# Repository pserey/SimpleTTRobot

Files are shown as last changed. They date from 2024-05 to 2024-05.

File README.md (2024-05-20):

# Simple TT Robot

> **Warning: This project is still in its early stages. Expect frequent updates and potential breaking changes to the codebase. The first real release will be available on the [Releases](https://github.com/pserey/SimpleTTRobot/releases) page.**

This open-source Table Tennis Robot project is designed to be a realistic, affordable, and easy-to-build robot for training purposes. Below, links to various sections of this repository are available.

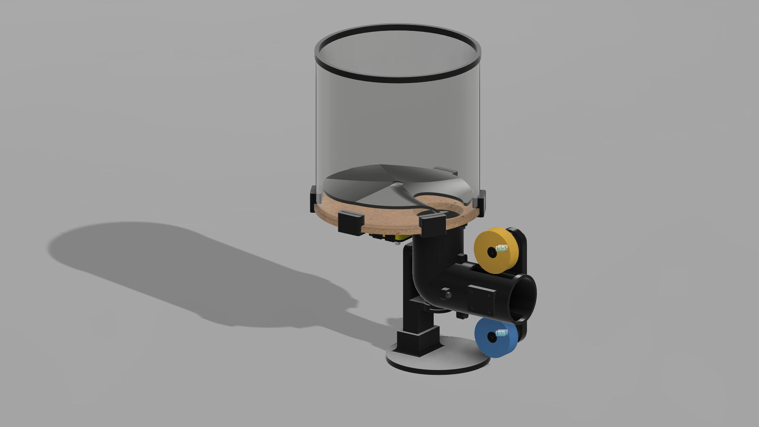
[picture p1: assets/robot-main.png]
robot

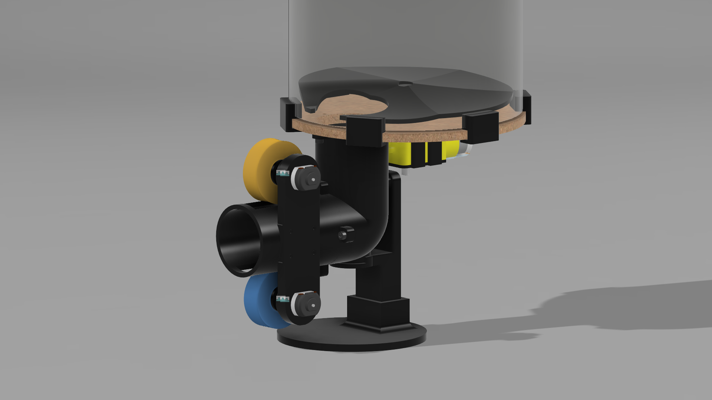
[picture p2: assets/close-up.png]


## Table of Contents

- [Introduction](#introduction)
- [Materials](#materials)
- [Build Guide](#build-guide)
- [Contributing](#contributing)
- [License](#license)

## Introduction

The Simple Table Tennis Robot was a personal project that tried to create a cheap alternative to every table tennis robot out there without losing on training capabilities. Now, the difference is it's an Open Source project 🏓

The main objective of this project is to use easy-to-find materials, electric components and microcontroller to make the building of it viable and cheap for anyone (mainly focused in the Brazilian market).

The whole design of the robot is heavily inspired in [this video](https://www.youtube.com/watch?v=-pSiuAdUKP4) from the channel [hiennguyenvan](https://www.youtube.com/@hiennguyenvan9777).

## Materials

### Physical/Hardware Materials
- 3D printed parts (CAD available)
- MDF laser-cut parts, or hand-cut if preferred (CAD available)
- IPong V300 flywheels (**the main focus now is developing non-propietary flywheels**)
- M3 and M4 screws and nuts
- Acrylic or cardboard sheets

### Electronic Components
- Arduino Nano or Uno microcontroller
- Connecting wires
- 1k and 2k resistors
- 2x 130-size 6V DC motors
- 1x 130-size 6V DC motor with gearbox
- 2x L298N H-Bridge motor drivers
- HC-05 Bluetooth receiver module
- LM393 Speed Sensor module
- 12V power supply

> Further detail of materials such as quantities will be added in a BOM format and updated at the README.md after the first release.

## Build Guide

> Build guide and circuit schema will be added with the first release. For now, only [build pictures](assets/build) are available.

## License

### CAD and documentation

The non-software components (3D CAD designs and documentation) are licensed under the Creative Commons Attribution-ShareAlike 4.0 International (CC BY-SA 4.0) License. See the [CAD-LICENSE](CAD-LICENSE.md) file for more details.

Shield: [][cc-by-sa]

This work is licensed under a
[Creative Commons Attribution-ShareAlike 4.0 International License][cc-by-sa].

[][cc-by-sa]

[cc-by-sa]: http://creativecommons.org/licenses/by-sa/4.0/
[cc-by-sa-image]: https://licensebuttons.net/l/by-sa/4.0/88x31.png
[cc-by-sa-shield]: https://img.shields.io/badge/License-CC%20BY--SA%204.0-lightgrey.svg

### Code

The software components of this project are licensed under the MIT License. See the [LICENSE](LICENSE.md) file for more details.

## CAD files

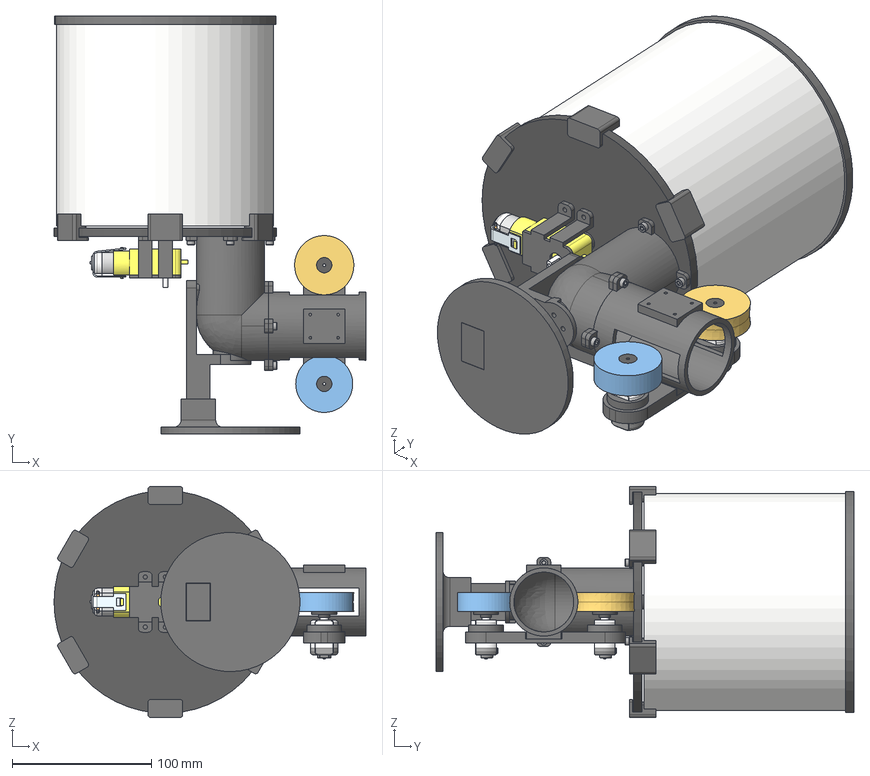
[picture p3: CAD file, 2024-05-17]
cad/step/Robot.step
224.2 x 300.5 x 166.1 mm
3V DC Electromotor x 2
Wheel Support
Wheel Support (1)
Entry Tube
Screws
Nuts
Base (1)
Disc
Motor Holder
Surface 1
Base (2)

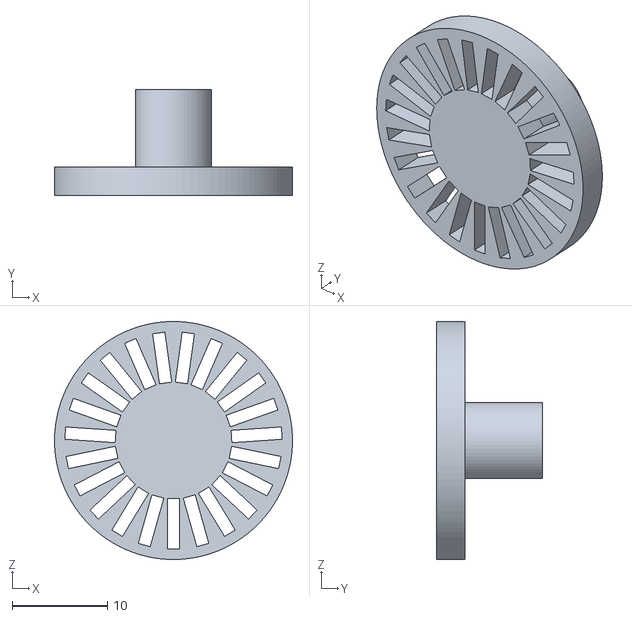
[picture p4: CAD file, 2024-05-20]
cad/stl/Encoder Wheel.stl
25.0 x 11.1 x 25.0

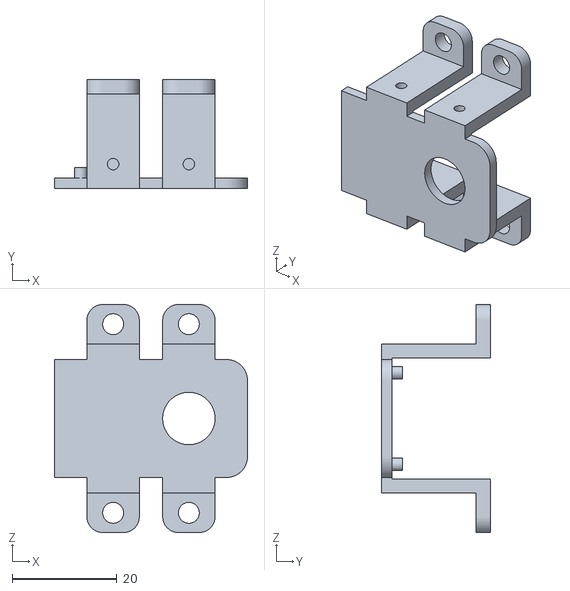
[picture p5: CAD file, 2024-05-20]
cad/stl/Motor Holder (Reservoir).stl
36.9 x 20.8 x 43.5

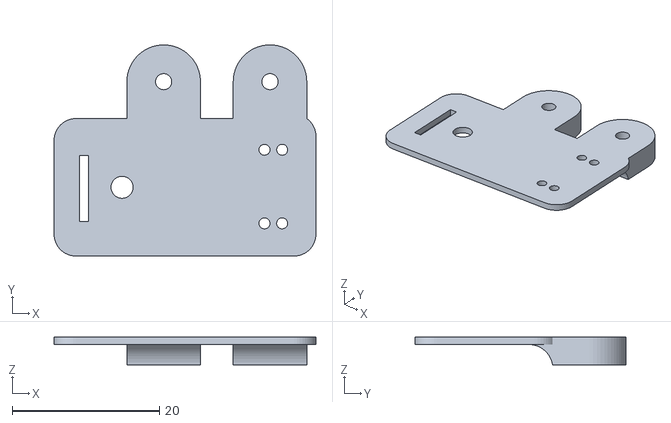
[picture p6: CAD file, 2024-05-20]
cad/stl/Encoder Support.stl
35.6 x 28.7 x 3.76

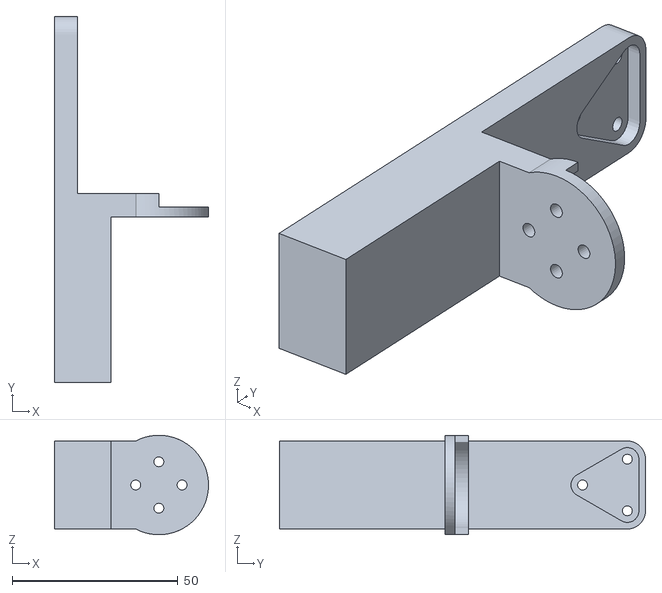
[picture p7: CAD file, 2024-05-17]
cad/stl/Base-Support.stl
46.5 x 110.5 x 30.0

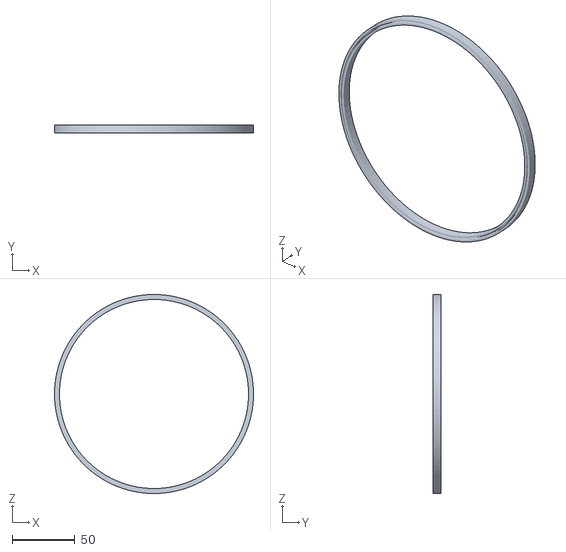
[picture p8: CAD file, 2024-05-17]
cad/stl/Wall Ring.stl
159.1 x 6.00 x 159.1

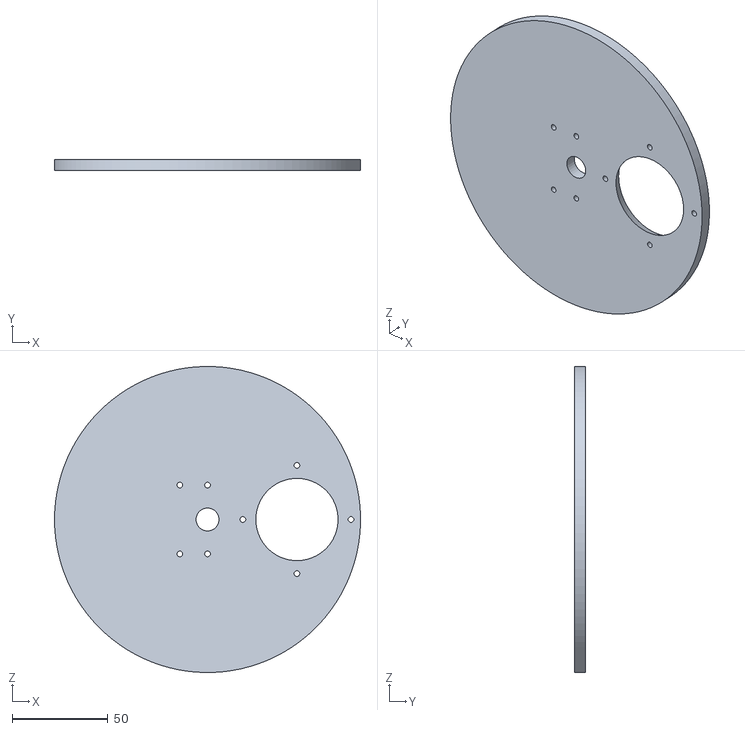
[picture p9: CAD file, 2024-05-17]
cad/stl/Reservoir Base.stl
160.0 x 6.00 x 160.0

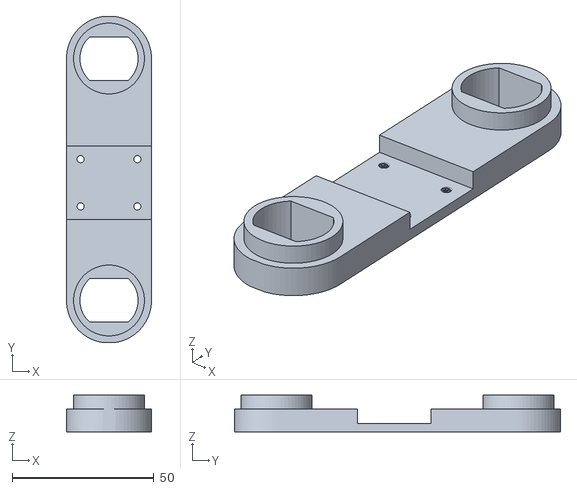
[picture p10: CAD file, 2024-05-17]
cad/stl/Motor Holder.stl
30.0 x 115.0 x 13.0

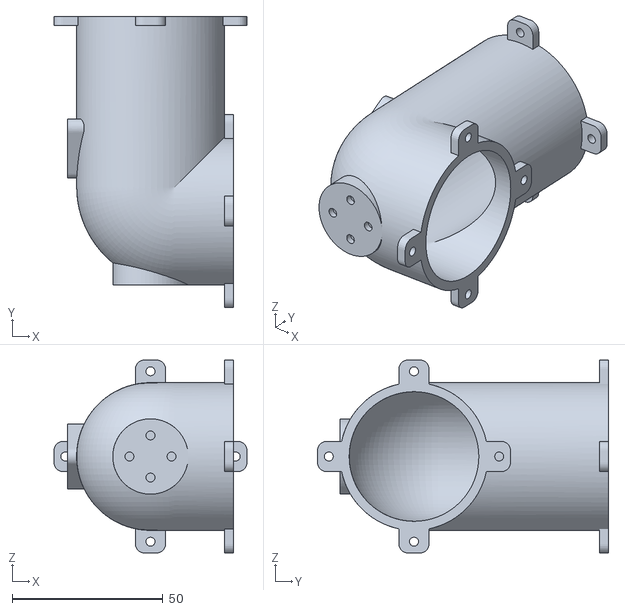
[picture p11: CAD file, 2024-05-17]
cad/stl/Entry Tube.stl
64.0 x 96.5 x 64.0

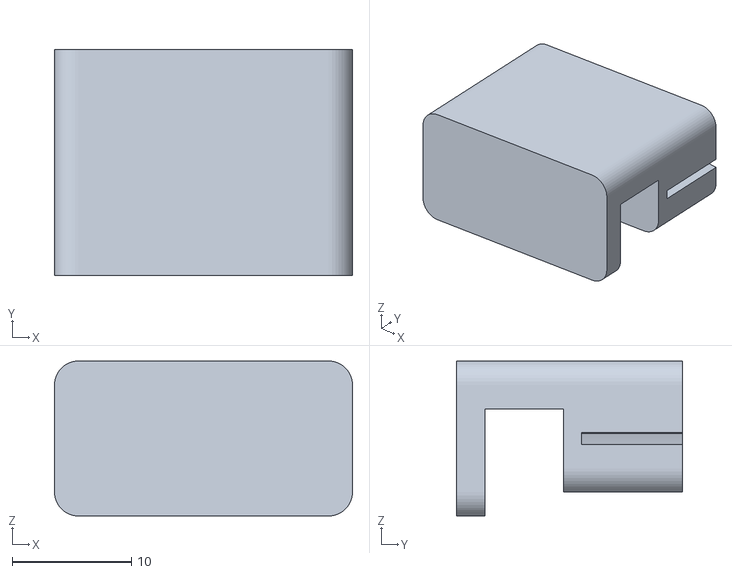
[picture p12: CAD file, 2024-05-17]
cad/stl/Wall Holder.stl
25.0 x 19.0 x 13.0

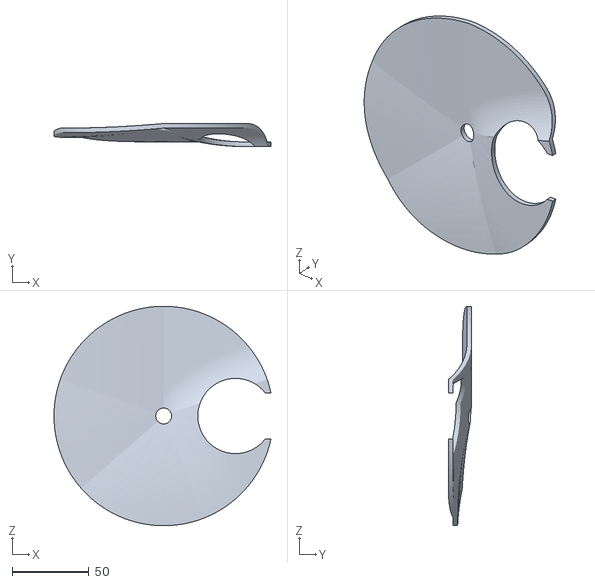
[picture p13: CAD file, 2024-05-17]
cad/stl/Disc.stl
141.4 x 15.0 x 143.0

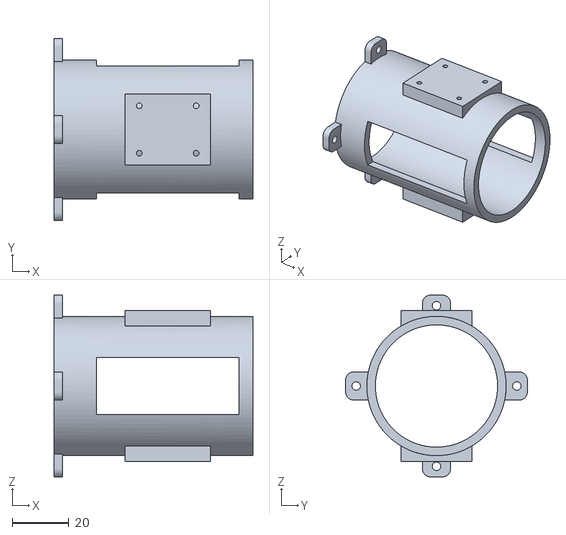
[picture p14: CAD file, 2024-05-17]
cad/stl/Motor Tube.stl
70.0 x 64.0 x 64.0

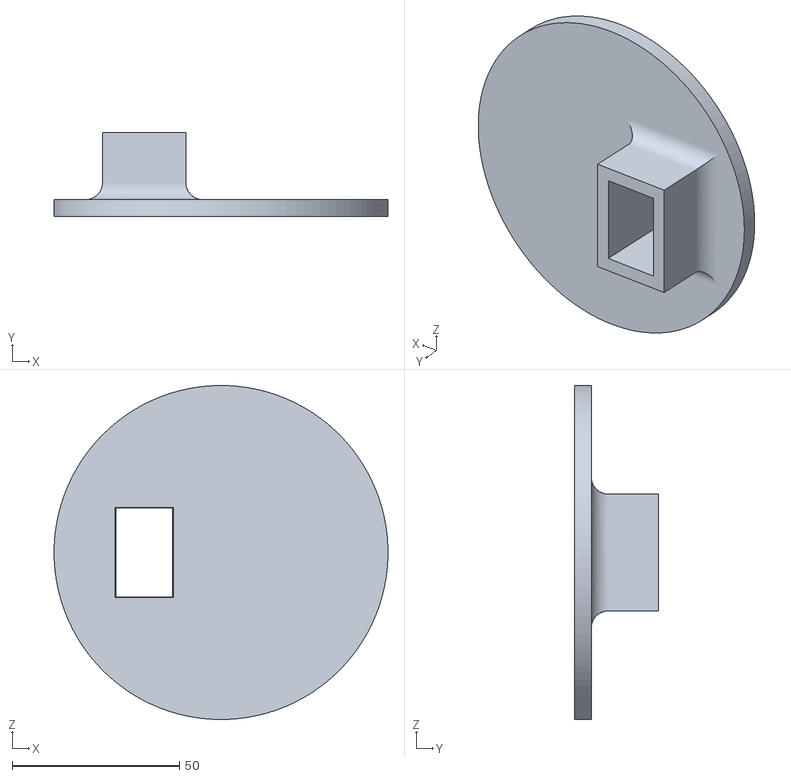
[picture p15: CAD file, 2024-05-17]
cad/stl/Base-Base.stl
100.0 x 25.0 x 100.0

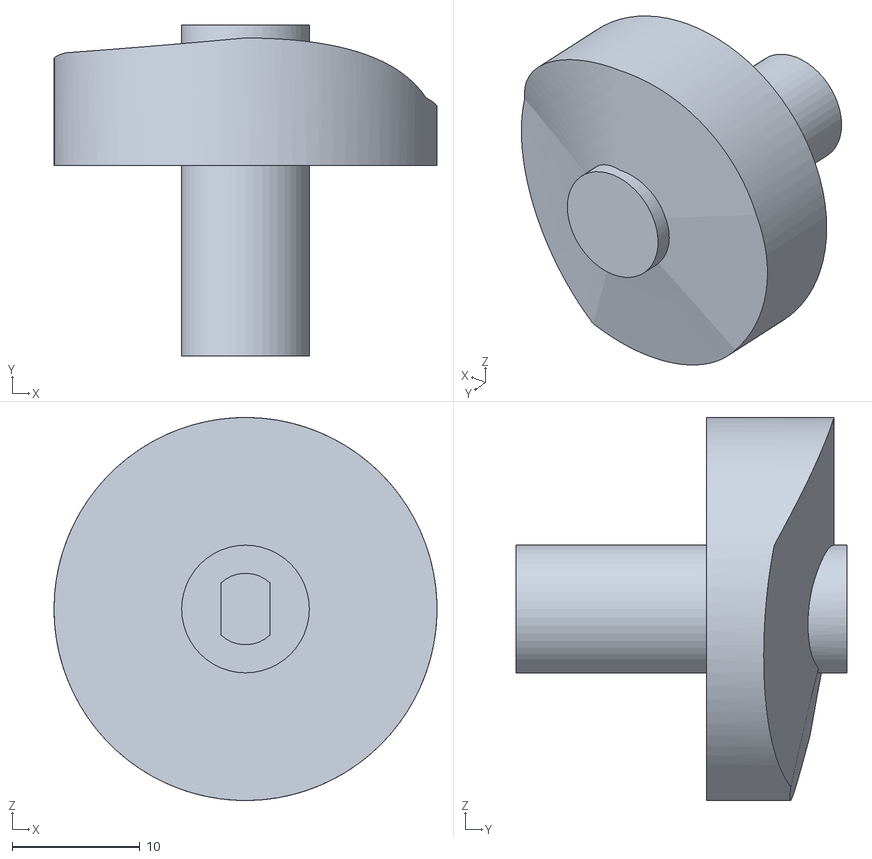
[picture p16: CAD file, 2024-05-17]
cad/stl/Pin.stl
30.0 x 25.9 x 30.0

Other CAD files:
cad/fusion/3V_DC_Electromotor.f3d
cad/fusion/Reduction_Box_Motor.f3d

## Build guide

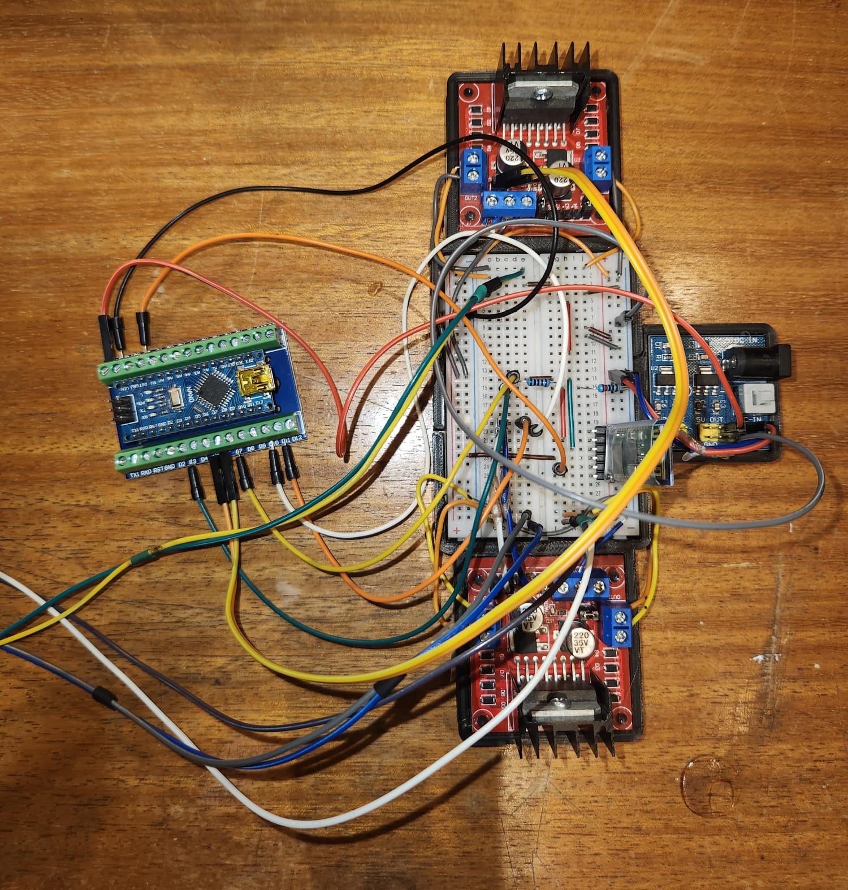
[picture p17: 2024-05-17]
assets/build/protoboard-build.jpg

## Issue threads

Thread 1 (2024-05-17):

Disc is not properly leading balls to shaft

pserey, 2024-05-17:
One of the "slices" of the disc is not inclined enough so that it leads the balls to the shaft. It results in making balls spin continuously on it without going to the shaft. A redesign using Fusion 360 is needed but I couldn't make it, so the current design uses fillets.

The problematic "slice" is the highlighted one.

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

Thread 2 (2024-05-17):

Reservoir base shaft might need to be larger

pserey, 2024-05-17:
The hole that connects the reservoir base to the entry tube seems to be too small. This results in the balls getting stuck between the disc and the edge of the hole when the disc spin frequency is high. Probably a bigger hole will solve this.

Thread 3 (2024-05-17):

Use non-proprietary flywheels

pserey, 2024-05-17:
It's **extremely** important that the flywheels are not proprietary like the ones being used currently. Testing materials with grip and elasticity such as TPU is needed to replace the current flywheels as soon as possible.

A copy of the IPong V300 wheels will work perfectly. After there is a working model, redesigns can be applied.

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

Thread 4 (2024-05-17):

Implement PID control over disc motor

pserey, 2024-05-17:
Implementing PID control over the disc motor is necessary to prevent balls stucking to the shaft, precision on frequency and adaptation to force needed with the increase of weight added with more balls.

pserey, 2024-05-20:
Simple PID control implemented in disc motor with LM393 speed sensor (optical encoder) with encoder disc. However, speed is still not 100% predictable and makes too high jumps.

- [ ] Needs implementation of PID tuning
- [ ] Encoder circuit support CAD file lacks precision (needed post processing)

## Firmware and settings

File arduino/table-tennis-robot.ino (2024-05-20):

#include "Arduino.h"
#include <SoftwareSerial.h>

const byte rxPin = 7;
const byte txPin = 3;
SoftwareSerial BTSerial(rxPin, txPin);

// define motor control pins (PWA)
const int back = 10;
const int top = 11; 

// frequency pins (PWA)
const int AFreq = 5;
const int BFreq = 6;

// encoder velocity
const int encPin = 2;
volatile int pulseCount = 0;
unsigned long previousMillis = 0;
const unsigned long interval = 500;
volatile int lastState = 0;

// PID
int globalRPM = 0;
const int targetRPM = 60;

// Kp, Ki, Kd
const float Kp = 0.75;
const float Ki = 0.2;
const float Kd = 0;

float previousError = 0;
float integral = 0;
float controlOutput = 0;

int topVel = 0;
int backVel = 0;
const int step = 5;
const int minVel = 25;
const int maxVel = 40;
int freqVelocity = 40;

// variables
int freqState = 0;
// at first implementation, i've decided to use string messages
// ending at ';' to communicate via HC-05
String messageBuffer = "";
String message = "";

int increaseVelocity(int velocity) {
  if (velocity < minVel) {
    return minVel;
  } else {

    if (velocity + step >= maxVel) {
      return maxVel;
    } else {
      return velocity + step;
    }
  }
}

int decreaseVelocity(int velocity) {
  if (velocity - step < minVel) {
    return 0;
  } else {
    return velocity - step;
  }
}

void startFrequency() {
  freqState = 1;

  analogWrite(AFreq, 40);
  delay(50);
  analogWrite(AFreq, freqVelocity);
}

void stopFrequency() {
  freqState = 0;
  analogWrite(AFreq, 0);
}

void unclogFrequency() {
  analogWrite(AFreq, 0);
  analogWrite(BFreq, 50);
  delay(70);
  analogWrite(BFreq, 0);
  startFrequency();
}

void calculateRPM() {
  int pulses = pulseCount;
  pulseCount = 0;
  // pulses * 60k (pulses in one minute)
  // 23 * interval (23 holes * interval inspected)
  globalRPM = (pulses * 60000) / (23 * interval);
}

void countPulse() {
  int currentState = digitalRead(encPin);
  if (currentState && !lastState) {
    pulseCount++;
  }
  lastState = currentState;
}

void makePID() {
  int error = targetRPM - globalRPM;
  integral += error * (interval / 1000.0); // integral term
  float derivative = (error - previousError) / (interval / 1000.0); // derivative term

  float rawOutput = (Kp * error) + (Ki * integral) + (Kd * derivative); // PID formula
  previousError = error; // Update previous error

  // Smooth the control output with a low-pass filter
  const float alpha = 0.1; // Smoothing factor (0 < alpha <= 1)
  controlOutput = (alpha * rawOutput) + ((1 - alpha) * controlOutput);

  // Limit the rate of change of the frequency velocity
  const float maxChangeRate = 10; // Maximum change rate per interval
  float newFreqVelocity = freqVelocity + constrain(controlOutput, -maxChangeRate, maxChangeRate);

  // Constrain the new frequency velocity to be within allowed limits
  freqVelocity = constrain(newFreqVelocity, 40, 60);

  // Update motor speed
  analogWrite(AFreq, freqVelocity);

  // Print debug information
  Serial.print("Target RPM: ");
  Serial.print(targetRPM);
  Serial.print(" | Current RPM: ");
  Serial.print(globalRPM);
  Serial.print(" | PID Output: ");
  Serial.print(controlOutput);
  Serial.print(" | Frequency Velocity: ");
  Serial.println(freqVelocity);
}

void setup() {
  pinMode(top, OUTPUT);
  pinMode(back, OUTPUT);
  pinMode(AFreq, OUTPUT);
  pinMode(BFreq, OUTPUT);
  pinMode(txPin, OUTPUT);
  pinMode(rxPin, INPUT);
  pinMode(encPin, INPUT);
  BTSerial.begin(9600);
  Serial.begin(9600);
  attachInterrupt(digitalPinToInterrupt(encPin), countPulse, RISING);
}

void loop() {


  unsigned long currentMillis = millis();

  if (currentMillis - previousMillis >= interval) {
    previousMillis = currentMillis;
    calculateRPM();
    if (freqState) {
      makePID();
    }
  }

  while (BTSerial.available() > 0) {
    char data = (char) BTSerial.read();
    messageBuffer += data;

    // other spin of frequency always turned off
    analogWrite(BFreq, 0);

    if (data == ';') {
      message = messageBuffer;
      messageBuffer = "";

      if (message == "TOPSPIN+1;") {

        if (!topVel) {
          analogWrite(top, 50);
          delay(100);
        }

        topVel = increaseVelocity(topVel);

        analogWrite(top, topVel);
        Serial.println(topVel);
      } else if (message == "BACKSPIN+1;") {

        if (!backVel) {
          analogWrite(back, 50);
          delay(100);
        }

        backVel = increaseVelocity(backVel);

        analogWrite(back, backVel);
        Serial.println(backVel);
      } else if (message == "STOP_ALL;") {
        stopFrequency();

        backVel = 0;
        topVel = 0;

        analogWrite(top, backVel);
        analogWrite(back, topVel);
        analogWrite(BFreq, 0);
      } else if (message == "BACKSPIN-1;") {

        backVel = decreaseVelocity(backVel);

        analogWrite(back, backVel);
        Serial.println(backVel);
      } else if (message == "TOPSPIN-1;") {

        topVel = decreaseVelocity(topVel);

        analogWrite(top, topVel);
        Serial.println(topVel);
      } else if (message == "FREQ;") {

        if (!freqState) {
          startFrequency();
        } else {
          stopFrequency();
        }
      } else if (message == "UNC;") {
        unclogFrequency();
      }
    }

  }
}

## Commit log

2024-05-17 add: STL files
    [Base-Base.stl, Base-Support.stl, Disc.stl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]
2024-05-17 add: F3D and STEP files
    [3V_DC_Electromotor.f3d, Reduction_Box_Motor.f3d, Robot.step]
2024-05-17 add: arduino code
2024-05-20 add: initial PID code and encoder CAD files
    [Encoder Support.stl, Encoder Wheel.stl, Motor Holder (Reservoir).stl]
